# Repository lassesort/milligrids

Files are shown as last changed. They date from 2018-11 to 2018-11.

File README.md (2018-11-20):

# Milligrids
11hp version of Grids (topographic drum sequencer eurorack module) by Mutable Instruments

# NOTICE
IF YOU BUILD THIS DO NOT BOTHER OLIVIER GILLET, MUTABLE INSTRUMENTS or THE MUTABLE INSTRUMENTS FORUM WITH QUESTIONS! JUST DON'T! 

I might help you. But my priorities are in this order: my kids, my spouse, my job, my jobby, my mental health, looking out of the window, finishing my pile of synth related pcbs, watching videos on Youtube about country borders, manufacturing processes and cyclists from the 80s and 90s, and finally, somewhere close to the end of this list: helping you when you're failing at programming a Milligrids or needing help finding alternatives for parts in the BOM. ;)

# License
Code (AVR projects): GPL3.0.

Hardware: cc-by-sa-3.0

Grids: https://mutable-instruments.net/modules/grids/

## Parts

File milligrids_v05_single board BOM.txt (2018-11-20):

Partlist exported from C:/Users/Lasse/Documents/eagle/DIY FUN/DIY Grids/milligrids_v05_single board.sch at 20-11-2018 23:39:35

Part Value                   Device                  Package                 Description                                       
C1   10n                     C0805                   C0805                   Capacitor 0805 Package                            
C2   10n                     C0805                   C0805                   Capacitor 0805 Package                            
C3   10n                     C0805                   C0805                   Capacitor 0805 Package                            
C4   10n                     C0603                   C0603                   Capacitor 0603 Package                            
C5   10n                     C0603                   C0603                   Capacitor 0603 Package                            
C6   10n                     C0603                   C0603                   Capacitor 0603 Package 
  For C4, C5, C6 0805 package is OK

C7   22u                     CPOL-USC                PANASONIC_C             POLARIZED CAPACITOR, American symbol              
C8   100n                    C0805                   C0805                   Capacitor 0805 Package                            
C9   100n                    C0805                   C0805                   Capacitor 0805 Package                            
C10  18p                     C0603                   C0603                   Capacitor 0603 Package                            
C11  18p                     C0603                   C0603                   Capacitor 0603 Package                            
C12  22u                     CPOL-USC                PANASONIC_C             POLARIZED CAPACITOR, American symbol              
C13  100n                    C0805                   C0805                   Capacitor 0805 Package                            
C14  100n                    C0805                   C0805                   Capacitor 0805 Package                            
C15  100n                    C0805                   C0805                   Capacitor 0805 Package                            
C16  100n                    C0805                   C0805                   Capacitor 0805 Package                            
C17  100n                    C0805                   C0805                   Capacitor 0805 Package                            
C18  100n                    C0805                   C0805                   Capacitor 0805 Package                            
C19  100n                    C0805                   C0805                   Capacitor 0805 Package                            
C20  100n                    C0805                   C0805                   Capacitor 0805 Package                            
C21  100n                    C0805                   C0805                   Capacitor 0805 Package                            
C22  470n                    C0805                   C0805                   Capacitor 0805 Package                            
D1   1N5819HW                DIODE-SOD123            SOD123                  DIODE                                             
IC1  MCP6001T-E/OT           MCP6001T-E/OT           SOT23-5                                                                   
IC2  MCP6001T-E/OT           MCP6001T-E/OT           SOT23-5                                                                   
IC3  MCP6001T-E/OT           MCP6001T-E/OT           SOT23-5                                                                   
IC4  MCP6001T-E/OT           MCP6001T-E/OT           SOT23-5                                                                   
IC5  MCP6001T-E/OT           MCP6001T-E/OT           SOT23-5                                                                   
IC6  MCP6001T-E/OT           MCP6001T-E/OT           SOT23-5                                                                   
IC7  LM1117-5.0              REG1117                 SOT223                  800mA and 1A Low Dropout (LDO) Positive Regulator 
IC8  74HC595D                74HC595D                SO16                    8-bit SHIFT REGISTER, output latch                
IC9  LM4040 5.0V             LM4041C12DBZ            DBZ_R-PDSO-G3           PRECISION MICROPOWER SHUNT VOLTAGE REFERENCE      
J1   WQP-PJ301M6(THONKICONN) WQP-PJ301M6(THONKICONN) WQP-PJ301M6(THONKICONN)                                                   
J2   WQP-PJ301M6(THONKICONN) WQP-PJ301M6(THONKICONN) WQP-PJ301M6(THONKICONN)                                                   
J3   WQP-PJ301M6(THONKICONN) WQP-PJ301M6(THONKICONN) WQP-PJ301M6(THONKICONN)                                                   
J4   WQP-PJ301M6(THONKICONN) WQP-PJ301M6(THONKICONN) WQP-PJ301M6(THONKICONN)                                                   
J5   WQP-PJ301M6(THONKICONN) WQP-PJ301M6(THONKICONN) WQP-PJ301M6(THONKICONN)                                                   
J6   WQP-PJ301M6(THONKICONN) WQP-PJ301M6(THONKICONN) WQP-PJ301M6(THONKICONN)                                                   
J7   WQP-PJ301M6(THONKICONN) WQP-PJ301M6(THONKICONN) WQP-PJ301M6(THONKICONN)                                                   
J8   WQP-PJ301M6(THONKICONN) WQP-PJ301M6(THONKICONN) WQP-PJ301M6(THONKICONN)                                                   
J9   52601-X10-8TLF          52601-X10-8TLF          52601-(X)10-8TLF                                                          
J10  54202-S0803LF           54202-S0803LF           54202-S0803LF                                                             
J11  WQP-PJ301M6(THONKICONN) WQP-PJ301M6(THONKICONN) WQP-PJ301M6(THONKICONN)                                                   
J12  WQP-PJ301M6(THONKICONN) WQP-PJ301M6(THONKICONN) WQP-PJ301M6(THONKICONN)                                                   
J13  WQP-PJ301M6(THONKICONN) WQP-PJ301M6(THONKICONN) WQP-PJ301M6(THONKICONN)                                                   
J14  WQP-PJ301M6(THONKICONN) WQP-PJ301M6(THONKICONN) WQP-PJ301M6(THONKICONN)                                                   
J15  WQP-PJ301M6(THONKICONN) WQP-PJ301M6(THONKICONN) WQP-PJ301M6(THONKICONN)                                                   
J16  WQP-PJ301M6(THONKICONN) WQP-PJ301M6(THONKICONN) WQP-PJ301M6(THONKICONN)                                                   
J17  54202-S0803LF           54202-S0803LF           54202-S0803LF                                                             
JP2  FIDUCIAL1X2             FIDUCIAL1X2             FIDUCIAL-1X2            Fiducial Alignment Points                         
JP3  FIDUCIAL1X2             FIDUCIAL1X2             FIDUCIAL-1X2            Fiducial Alignment Points                         
JP4  FIDUCIAL1X2             FIDUCIAL1X2             FIDUCIAL-1X2            Fiducial Alignment Points                         
JP5  FIDUCIAL1X2             FIDUCIAL1X2             FIDUCIAL-1X2            Fiducial Alignment Points                         
L1                           WE-CBF_0603             0603                    SMD EMI Suppression Ferrite Beads                 
Q1   MMBT3904LT1G            MMBT3904LT1G            SOT23-3                                                                   
Q2   MMBT3904LT1G            MMBT3904LT1G            SOT23-3                                                                   
Q3   20MHz                   CRYSTALHC49UP           HC49UP                  CRYSTAL                                           
R1   10k (x)                 SONGHUEI-RK0914         SONGHUEI-RK0914         SONG HUEI RK0914 9mm POTENTIOMETER                
R2   10k (y)                 SONGHUEI-RK0914         SONGHUEI-RK0914         SONG HUEI RK0914 9mm POTENTIOMETER                
R3   10k (chaos)             SONGHUEI-RK0914         SONGHUEI-RK0914         SONG HUEI RK0914 9mm POTENTIOMETER                
R4   100k                    R0603                   R0603                   Resistor 0603 Package                             
R5   1M                      R0603                   R0603                   Resistor 0603 Package                             
R6   100k                    R0603                   R0603                   Resistor 0603 Package                             
R7   100k                    R0603                   R0603                   Resistor 0603 Package                             
R8   100k                    R0603                   R0603                   Resistor 0603 Package                             
R9   100k                    R0603                   R0603                   Resistor 0603 Package                             
R10  100k                    R0603                   R0603                   Resistor 0603 Package                             
R11  100k                    R0603                   R0603                   Resistor 0603 Package                             
R12  100k                    R0603                   R0603                   Resistor 0603 Package                             
R13  100k                    R0603                   R0603                   Resistor 0603 Package                             
R14  100k                    R0603                   R0603                   Resistor 0603 Package                             
R15  10k                     R0805                   R0805                   Resistor 0805 Package                             
R16  100k                    R0603                   R0603                   Resistor 0603 Package                             
R17  100k                    R0603                   R0603                   Resistor 0603 Package                             
R18  100k                    R0603                   R0603                   Resistor 0603 Package                             
R19  100k                    R0603                   R0603                   Resistor 0603 Package                             
R20  1M                      R0603                   R0603                   Resistor 0603 Package                             
R21  10k                     R0805                   R0805                   Resistor 0805 Package                             
R22  100k                    R0603                   R0603                   Resistor 0603 Package                             
R23  100k                    R0603                   R0603                   Resistor 0603 Package                             
R24  100k                    R0603                   R0603                   Resistor 0603 Package                             
R25  100k                    R0603                   R0603                   Resistor 0603 Package                             
R26  100k                    R0603                   R0603                   Resistor 0603 Package                             
R27  100k                    R0603                   R0603                   Resistor 0603 Package                             
R28  100k                    R0603                   R0603                   Resistor 0603 Package                             
R29  100k                    R0603                   R0603                   Resistor 0603 Package                             
R30  100k                    R0603                   R0603                   Resistor 0603 Package                             
R31  100k                    R0603                   R0603                   Resistor 0603 Package                             
R32  100k                    R0603                   R0603                   Resistor 0603 Package                             
R33  100k                    R0603                   R0603                   Resistor 0603 Package                             
R34  10k                     R0805                   R0805                   Resistor 0805 Package                             
R35  1k5                     R0805                   R0805                   Resistor 0805 Package                             
R36  1k5                     R0805                   R0805                   Resistor 0805 Package                             
R37  1k5                     R0805                   R0805                   Resistor 0805 Package                             
R38  10k (Clock)             BOURNS-PTL30            BOURNS-PTL30                                                              
R39  1k5                     R0805                   R0805                   Resistor 0805 Package                             
R40  10k (3)                 BOURNS-PTL30            BOURNS-PTL30                                                              
R41  10k                     R0805                   R0805                   Resistor 0805 Package                             
R42  1.0k                    R0805                   R0805                   Resistor 0805 Package                             
R43  1.0k                    R0805                   R0805                   Resistor 0805 Package                             
R44  1.0k                    R0805                   R0805                   Resistor 0805 Package                             
R45  10k (2)                 BOURNS-PTL30            BOURNS-PTL30                                                              
R46  1.0k                    R0805                   R0805                   Resistor 0805 Package                             
R47  1.0k                    R0805                   R0805                   Resistor 0805 Package                             
R48  1.0k                    R0805                   R0805                   Resistor 0805 Package                             
R49  10k (1)                 BOURNS-PTL30            BOURNS-PTL30                                                              
SW1  E-SWITCH-TL1105SPSP     E-SWITCH-TL1105SPSP     E-SWITCH-TL1105SP       E-SWITCH                                          
U1   ATMEGA328P-AU           ATMEGA168               TQFP32-08

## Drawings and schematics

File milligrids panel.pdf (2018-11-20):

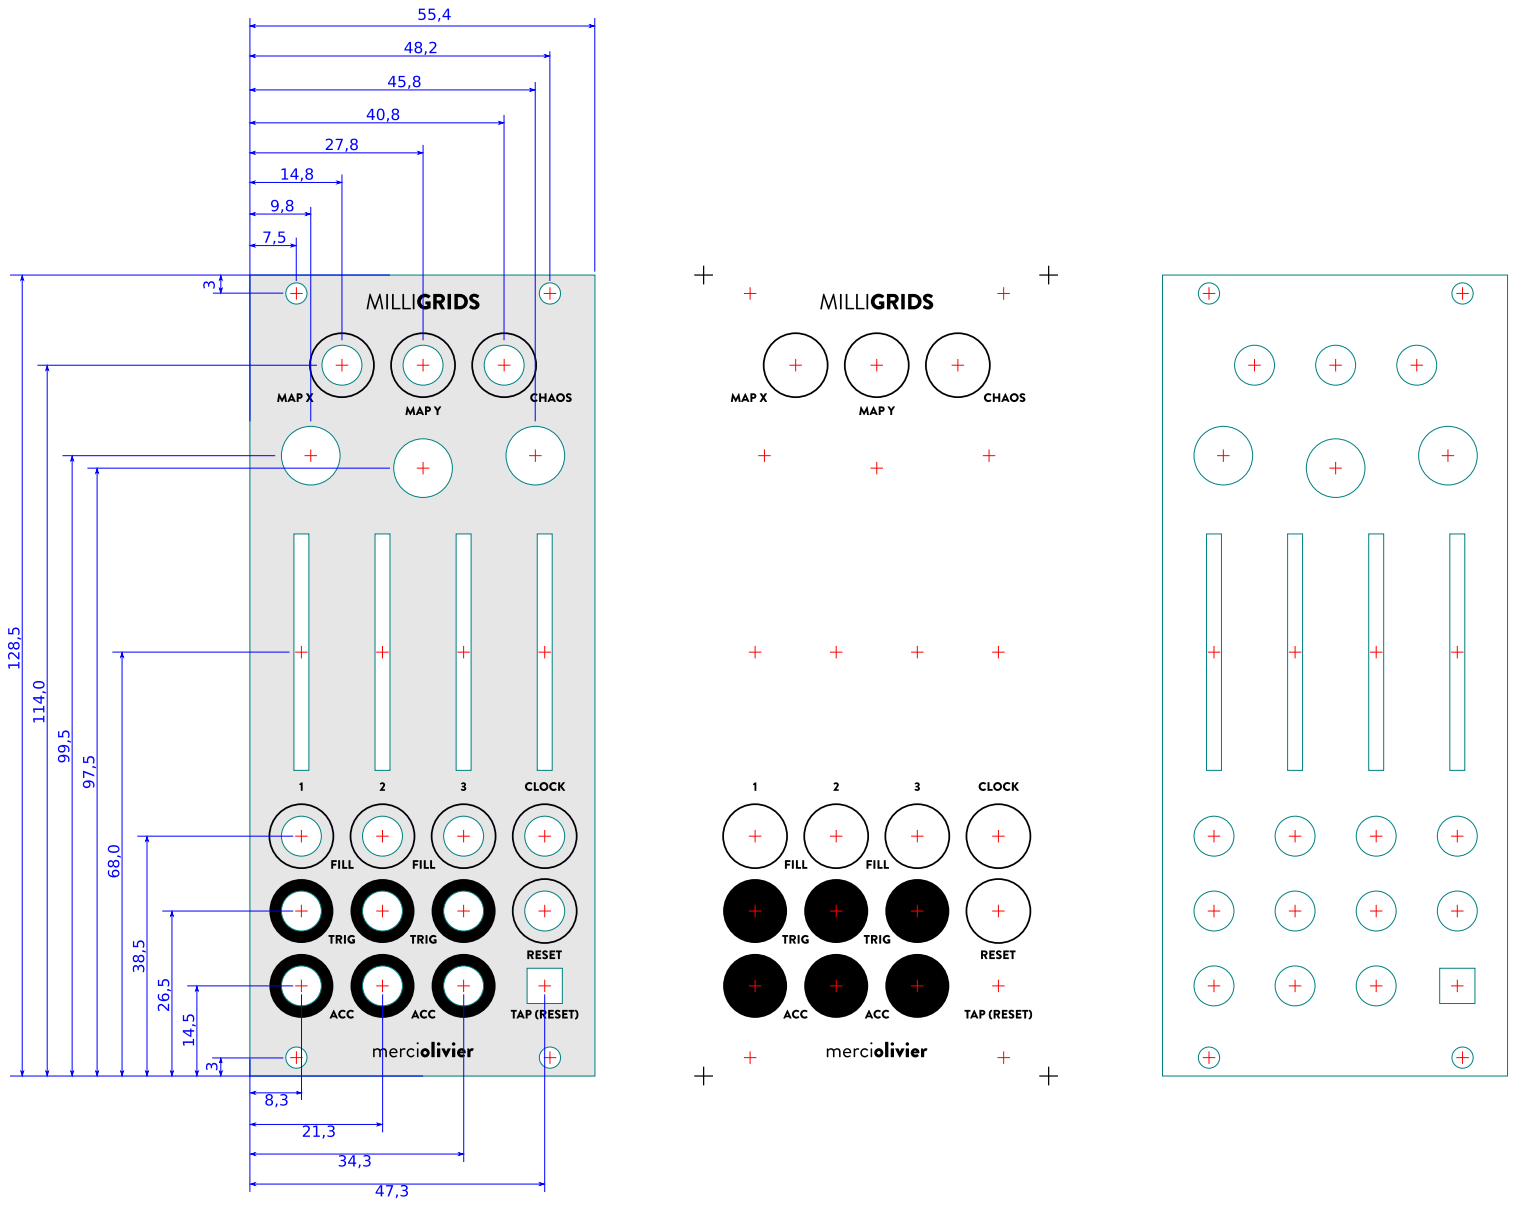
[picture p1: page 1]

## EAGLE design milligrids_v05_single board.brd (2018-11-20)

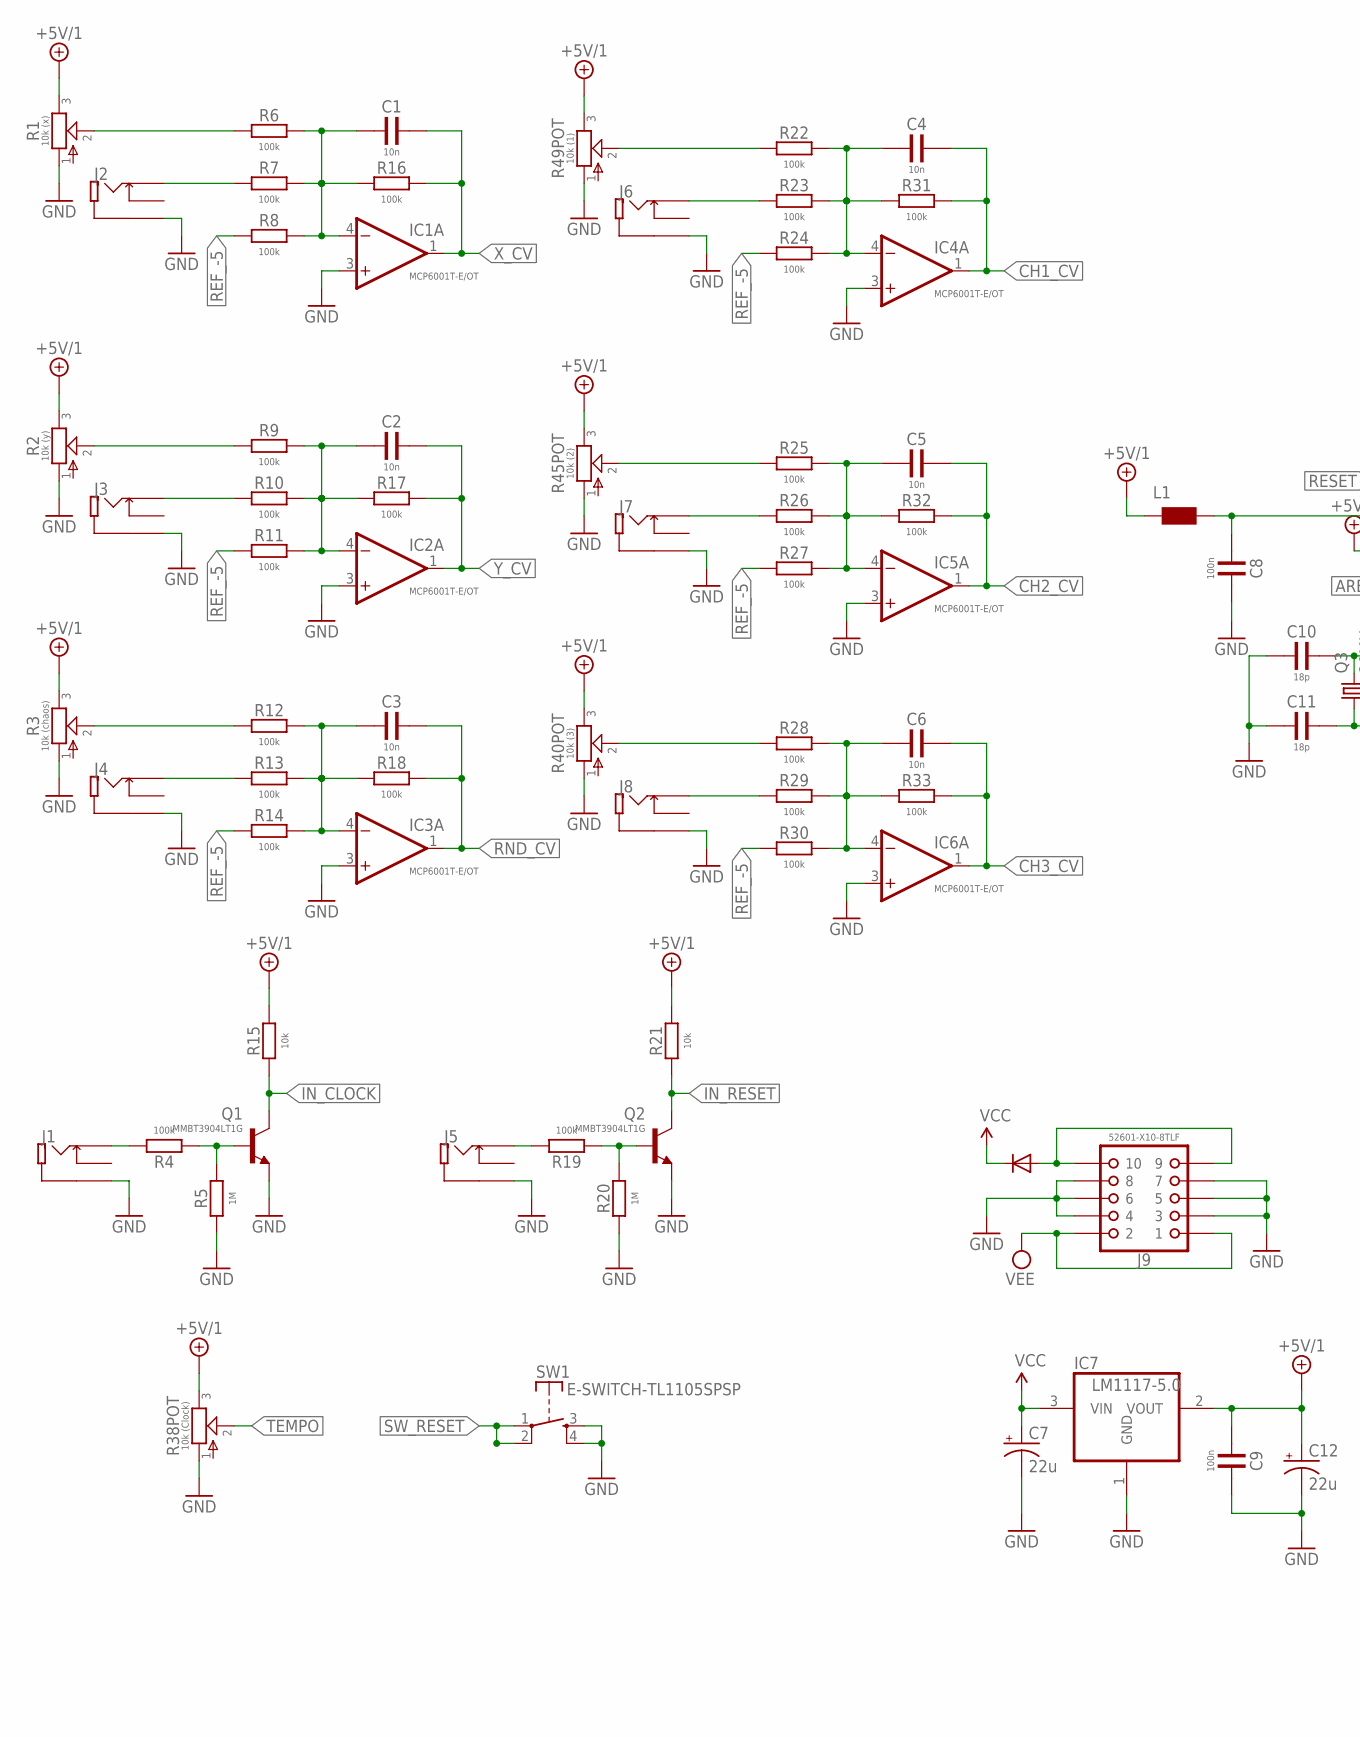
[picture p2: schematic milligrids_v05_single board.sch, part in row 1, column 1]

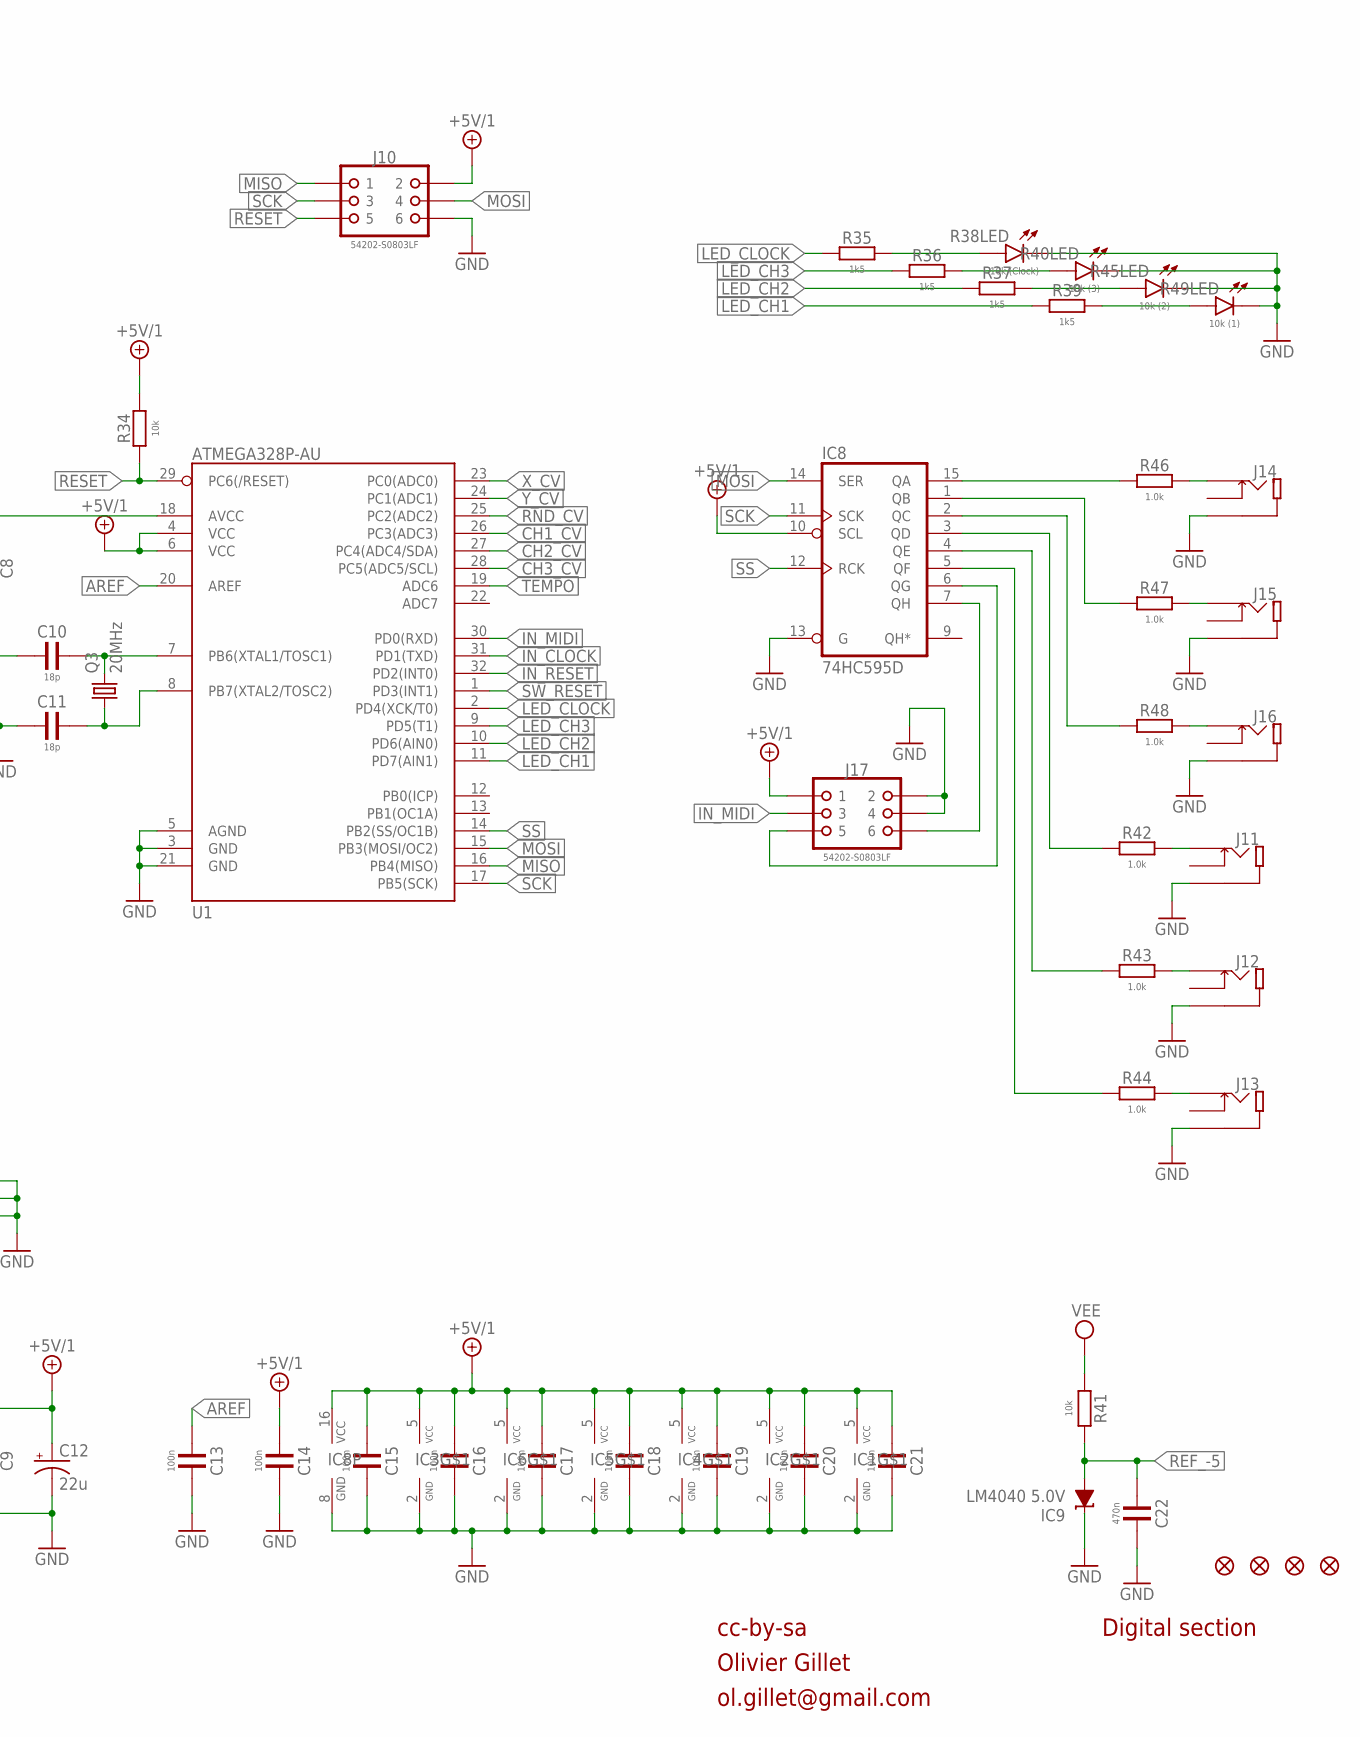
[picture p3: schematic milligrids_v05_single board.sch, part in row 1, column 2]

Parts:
C1, C2, C3: 10n; C0805
C4, C5, C6: 10n; C0603
C7, C12: 22u; PANASONIC_C
C8, C9, C13, C14, C15, C16, C17, C18, C19, C20, C21: 100n; C0805
C10, C11: 18p; C0603
C22: 470n; C0805
D1: 1N5819HW; SOD123
IC1, IC2, IC3, IC4, IC5, IC6: MCP6001T-E/OT; SOT23-5
IC7: LM1117-5.0; SOT223
IC8: 74HC595D; SO16
IC9: LM4040 5.0V; DBZ_R-PDSO-G3
J1, J2, J3, J4, J5, J6, J7, J8, J11, J12, J13, J14, J15, J16: WQP-PJ301M6(THONKICONN)
J9: 52601-X10-8TLF; 52601-(X)10-8TLF
J10, J17: 54202-S0803LF
JP2, JP3, JP4, JP5: FIDUCIAL1X2; FIDUCIAL-1X2
L1: WE-CBF_0603; 0603
Q1, Q2: MMBT3904LT1G; SOT23-3
Q3: 20MHz; HC49UP
R1: 10k (x); SONGHUEI-RK0914
R2: 10k (y); SONGHUEI-RK0914
R3: 10k (chaos); SONGHUEI-RK0914
R4, R6, R7, R8, R9, R10, R11, R12, R13, R14, R16, R17, R18, R19, R22, R23, R24, R25, R26, R27, R28, R29, R30, R31, R32, R33: 100k; R0603
R5, R20: 1M; R0603
R15, R21, R34, R41: 10k; R0805
R35, R36, R37, R39: 1k5; R0805
R38: 10k (Clock); BOURNS-PTL30
R40: 10k (3); BOURNS-PTL30
R42, R43, R44, R46, R47, R48: 1.0k; R0805
R45: 10k (2); BOURNS-PTL30
R49: 10k (1); BOURNS-PTL30
SW1: E-SWITCH-TL1105SPSP; E-SWITCH-TL1105SP
U1: ATMEGA328P-AU; TQFP32-08

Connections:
+5V/1: C9.1, C12.+, C14.1, C15.1, C16.1, C17.1, C18.1, C19.1, C20.1, C21.1, IC1.5 (VCC), IC2.5 (VCC), IC3.5 (VCC), IC4.5 (VCC), IC5.5 (VCC), IC6.5 (VCC), IC7.2 (VOUT), IC8.10 (SCL), IC8.16 (VCC), J10.2, J17.1, L1.1, R1.3, R2.3, R3.3, R15.2, R21.2, R34.2, R38.3, R40.3, R45.3, R49.3, U1.4 (VCC), U1.6 (VCC)
AREF: C13.1, U1.20 (AREF)
CH1_ACC: J11.P3 (3), R42.2
CH1_CV: C4.2, IC4.1 (OUT), R31.2, U1.26 (PC3(ADC3))
CH1_JACK: J6.P3 (3), R23.1
CH1_LED: R39.2, R49.B (A)
CH1_POT: R22.1, R49.2
CH1_TRIG: J14.P3 (3), R46.2
CH2_ACC: J12.P3 (3), R43.2
CH2_CV: C5.2, IC5.1 (OUT), R32.2, U1.27 (PC4(ADC4/SDA))
CH2_JACK: J7.P3 (3), R26.1
CH2_LED: R37.2, R45.B (A)
CH2_POT: R25.1, R45.2
CH2_TRIG: J15.P3 (3), R47.2
CH3_ACC: J13.P3 (3), R44.2
CH3_CV: C6.2, IC6.1 (OUT), R33.2, U1.28 (PC5(ADC5/SCL))
CH3_JACK: J8.P3 (3), R29.1
CH3_LED: R36.2, R40.B (A)
CH3_TRIG: J16.P3 (3), R48.2
CH_POT: R28.1, R40.2
CLK_LED: R35.2, R38.B (A)
CLOCK_OUT: IC8.6 (QG), J17.5
GATE1_IN: J1.P3 (3), R4.2
GATE2_IN: J5.P3 (3), R19.2
GND: C7.-, C8.2, C9.2, C10.1, C11.1, C12.-, C13.2, C14.2, C15.2, C16.2, C17.2, C18.2, C19.2, C20.2, C21.2, C22.2, IC1.2 (GND), IC1.3 (+IN), IC2.2 (GND), IC2.3 (+IN), IC3.2 (GND), IC3.3 (+IN), IC4.2 (GND), IC4.3 (+IN), IC5.2 (GND), IC5.3 (+IN), IC6.2 (GND), IC6.3 (+IN), IC7.1 (GND), IC8.8 (GND), IC8.13 (G), IC9.1 (C), J1.P1 (1), J2.P1 (1), J3.P1 (1), J4.P1 (1), J5.P1 (1), J6.P1 (1), J7.P1 (1), J8.P1 (1), J9.3, J9.4, J9.5, J9.6, J9.7, J9.8, J10.6, J11.P1 (1), J12.P1 (1), J13.P1 (1), J14.P1 (1), J15.P1 (1), J16.P1 (1), J17.2, J17.4, Q1.2 (E), Q2.2 (E), R1.1, R2.1, R3.1, R5.1, R20.1, R38.1, R38.E (K), R40.1, R40.E (K), R45.1, R45.E (K), R49.1, R49.E (K), SW1.3, SW1.4, U1.3 (GND), U1.5 (AGND), U1.21 (GND)
IN_CLOCK: Q1.3 (C), R15.1, U1.31 (PD1(TXD))
IN_MIDI: J17.3, U1.30 (PD0(RXD))
IN_RESET: Q2.3 (C), R21.1, U1.32 (PD2(INT0))
LED_CH1: R39.1, U1.11 (PD7(AIN1))
LED_CH2: R37.1, U1.10 (PD6(AIN0))
LED_CH3: R36.1, U1.9 (PD5(T1))
LED_CLOCK: R35.1, U1.2 (PD4(XCK/T0))
MISO: J10.1, U1.16 (PB4(MISO))
MOSI: IC8.14 (SER), J10.4, U1.15 (PB3(MOSI/OC2))
unnamed: Q1.1 (B), R4.1, R5.2
unnamed: Q2.1 (B), R19.1, R20.2
unnamed: D1.A, J9.9, J9.10
unnamed: C2.1, IC2.4 (-IN), R9.2, R10.2, R11.2, R17.1
unnamed: C3.1, IC3.4 (-IN), R12.2, R13.2, R14.2, R18.1
unnamed: C4.1, IC4.4 (-IN), R22.2, R23.2, R24.2, R31.1
unnamed: C5.1, IC5.4 (-IN), R25.2, R26.2, R27.2, R32.1
unnamed: C6.1, IC6.4 (-IN), R28.2, R29.2, R30.2, R33.1
unnamed: IC8.15 (QA), R46.1
unnamed: IC8.1 (QB), R47.1
unnamed: C1.1, IC1.4 (-IN), R6.2, R7.2, R8.2, R16.1
unnamed: IC8.2 (QC), R48.1
unnamed: IC8.3 (QD), R42.1
unnamed: IC8.4 (QE), R43.1
unnamed: IC8.5 (QF), R44.1
unnamed: C8.1, L1.2, U1.18 (AVCC)
unnamed: C11.2, Q3.1, U1.8 (PB7(XTAL2/TOSC2))
unnamed: C10.2, Q3.2, U1.7 (PB6(XTAL1/TOSC1))
RANDOM_GATE: IC8.7 (QH), J17.6
REF_-5: C22.1, IC9.2 (A), R8.1, R11.1, R14.1, R24.1, R27.1, R30.1, R41.2
RESET: J10.5, R34.1, U1.29 (PC6(/RESET))
RND_CV: C3.2, IC3.1 (OUT), R18.2, U1.25 (PC2(ADC2))
RND_JACK: J4.P3 (3), R13.1
RND_POT: R3.2, R12.1
SCK: IC8.11 (SCK), J10.3, U1.17 (PB5(SCK))
SS: IC8.12 (RCK), U1.14 (PB2(SS/OC1B))
SW_RESET: SW1.1, SW1.2, U1.1 (PD3(INT1))
TEMPO: R38.2, U1.19 (ADC6)
VCC: C7.+, D1.C, IC7.3 (VIN)
VEE: J9.1, J9.2, R41.1
X_CV: C1.2, IC1.1 (OUT), R16.2, U1.23 (PC0(ADC0))
X_JACK: J2.P3 (3), R7.1
X_POT: R1.2, R6.1
Y_CV: C2.2, IC2.1 (OUT), R17.2, U1.24 (PC1(ADC1))
Y_JACK: J3.P3 (3), R10.1
Y_POT: R2.2, R9.1

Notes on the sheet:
cc-by-sa
Olivier Gillet
ol.gillet@gmail.com
Digital section

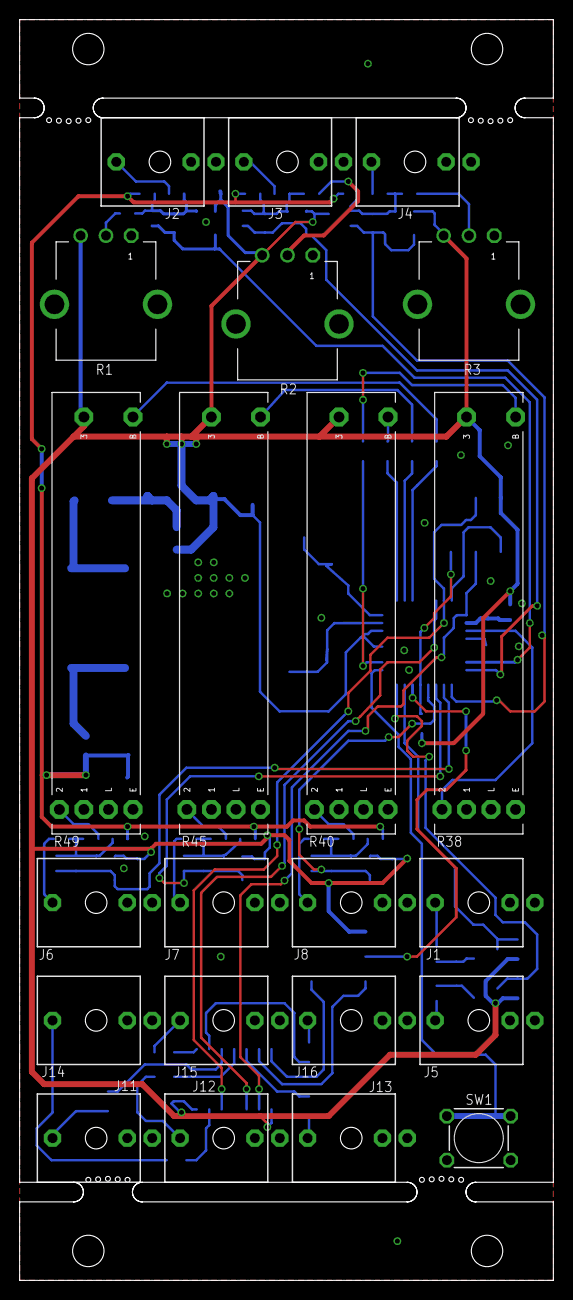
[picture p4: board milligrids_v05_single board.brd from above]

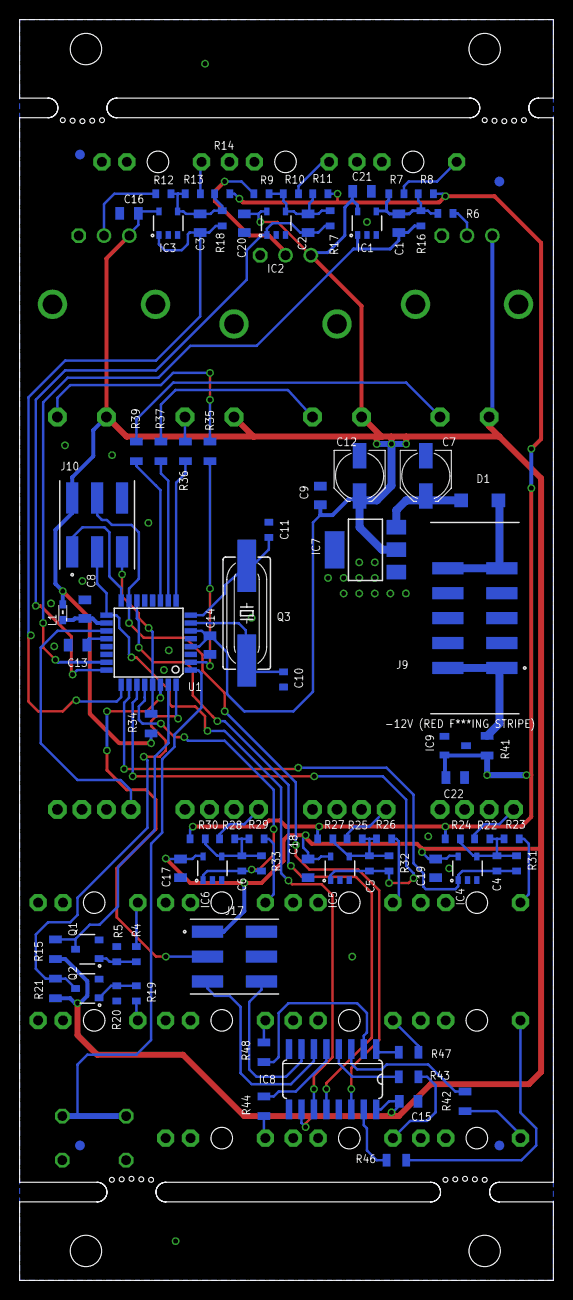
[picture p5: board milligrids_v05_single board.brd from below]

Board: 2 copper layers, 54.4 x 128.5 mm, 108 parts (86 on the bottom side), 70 nets.

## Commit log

2018-11-20 Rename milligrids_v05_single board.txt to milligrids_v05_single board BOM.txt
2018-11-20 Update milligrids_v05_single board BOM.txt
